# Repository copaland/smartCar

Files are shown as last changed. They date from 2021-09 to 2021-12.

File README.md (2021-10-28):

# smartCar
Arduino Bluetooth controlled 2WD smart Car

1. Ultrasonic sensor
2. Bluetooth controlled with Button App
3. Bluetooth controlled with Joystic App  

[AF Motor Shield Library] https://github.com/adafruit/Adafruit-Motor-Shield-library

https://arduino.esp8266.com/stable/package_esp8266com_index.json

https://github.com/stm32duino/BoardManagerFiles/raw/master/package_stmicroelectronics_index.json,https://mcudude.github.io/MiniCore/package_MCUdude_MiniCore_index.json,https://arduino.esp8266.com/stable/package_esp8266com_index.json

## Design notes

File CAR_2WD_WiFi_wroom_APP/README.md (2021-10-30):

 ##  2WD CAR ESP WiFi 버튼 제어 프로그램
 
Board : ESP-WROOM-02 D1  
Driver : TB6612  
Library : WiFiCar_TB6612  

D0  16 LED PULLUP 10K  
D1  5 TRIG  
D2  4 ECHO  
D3  0      FLASH  
D4  2      (SDA)  
D5  14 AIN (SCL)  
D6  12 APWM  
D7  13 BPWM  
D8  15 BIN PULLDOWN 10K   
D9  TX 1 RXD BT  
D10 RX 3 TXD BT  

* Board manager URL
https://arduino.esp8266.com/stable/package_esp8266com_index.json

* Board
LOLIN(Wemos) D1 & R2 & mini

* Library 
https://github.com/copaland/smartCar/blob/main/WiFiCar_TB6612-master.zip

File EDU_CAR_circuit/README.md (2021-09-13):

## ESP-WROOM-02 BASE Smat Car Kit

### 1.KiCad 설치 : 회로도 작성, PCB 설계
### 2.Arduino 설치 : Firmware 프로그래밍
### 3.MIT APP Inventor

### ESP-WROOM-02 PIN MAP
1-A0     SENS  
2-D1   5 TRIG  
3-D2   4 ECHO  
4-D3   0 LEFT SENS(FLASH)   
5-D4   2 RIGHT SENS(SDA)  
6-D5  14 AIN(SCL)  
7-D6  12 APWM   
8-D7  13 BPWM   
9-D8  15 BIN    
10-D9  3 RX  BT  
11-D10 1 TX  BT
13-D0 16 LED (Default)  

### Use KiCad virsion 5.1.10 
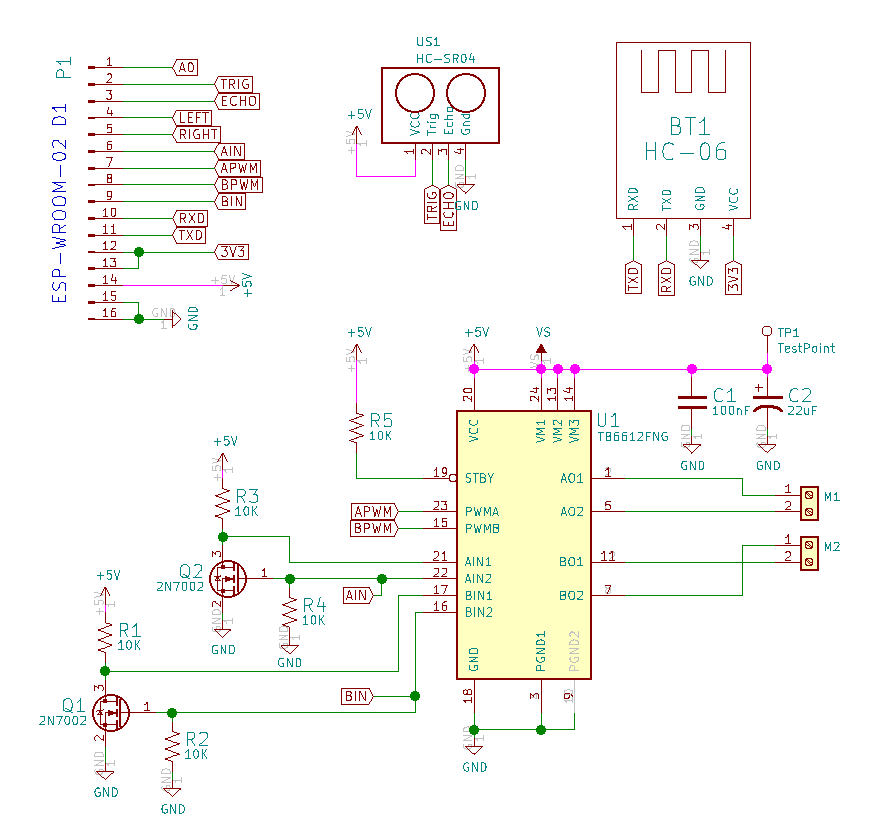
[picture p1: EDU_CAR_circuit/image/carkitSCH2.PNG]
회로도
  
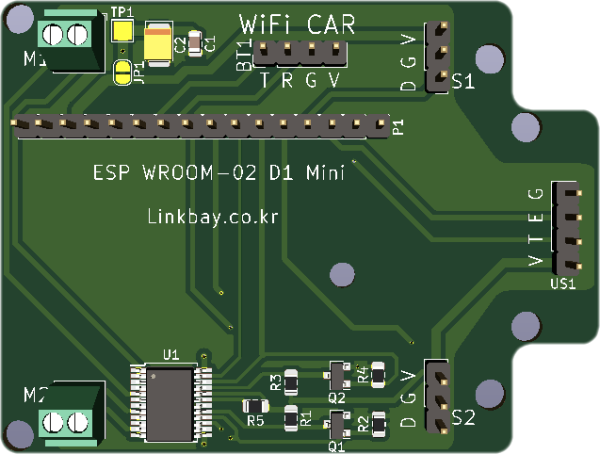
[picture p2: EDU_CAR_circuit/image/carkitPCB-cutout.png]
PCB
  
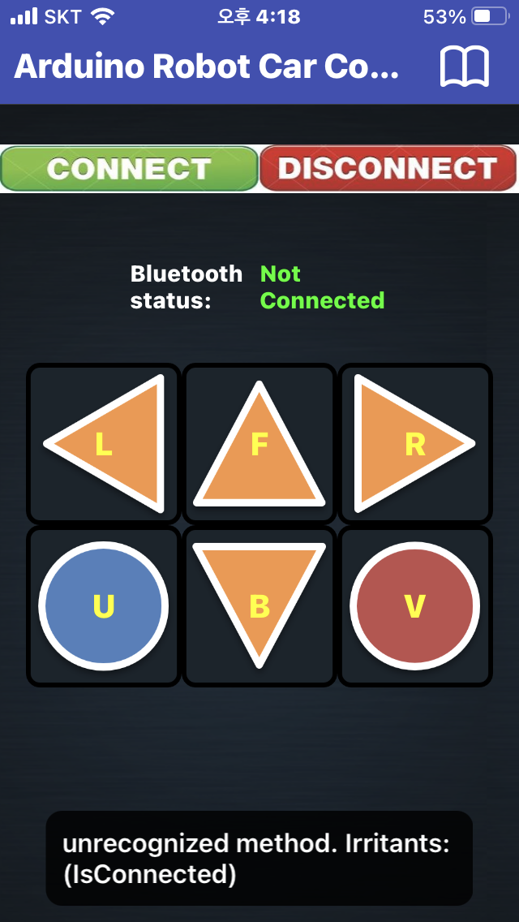
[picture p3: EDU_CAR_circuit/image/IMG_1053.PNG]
APP


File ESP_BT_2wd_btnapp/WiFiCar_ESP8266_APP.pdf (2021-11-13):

2021-11-13

1

# 3. IoT 앱 인벤터

## 김랑기 명장

# Smart IoT

## 학습내용

## 1. 앱인벤터 개요 2. 하드웨어 조립 및 테스트 3. 앱 인벤터 프로그램

학습목표
1. 아두이노로 모터를 제어하는 코딩을 작성할 수 있다. 2. 모터제어 하드웨어를 조립하고 테스트할 수 있다. 3. 앱인벤터 프로그램으로 앱을 만들고 원격으로 제어 할 수 있다. | 2

1

2

2

1

# 앱 인벤터의 개요

3

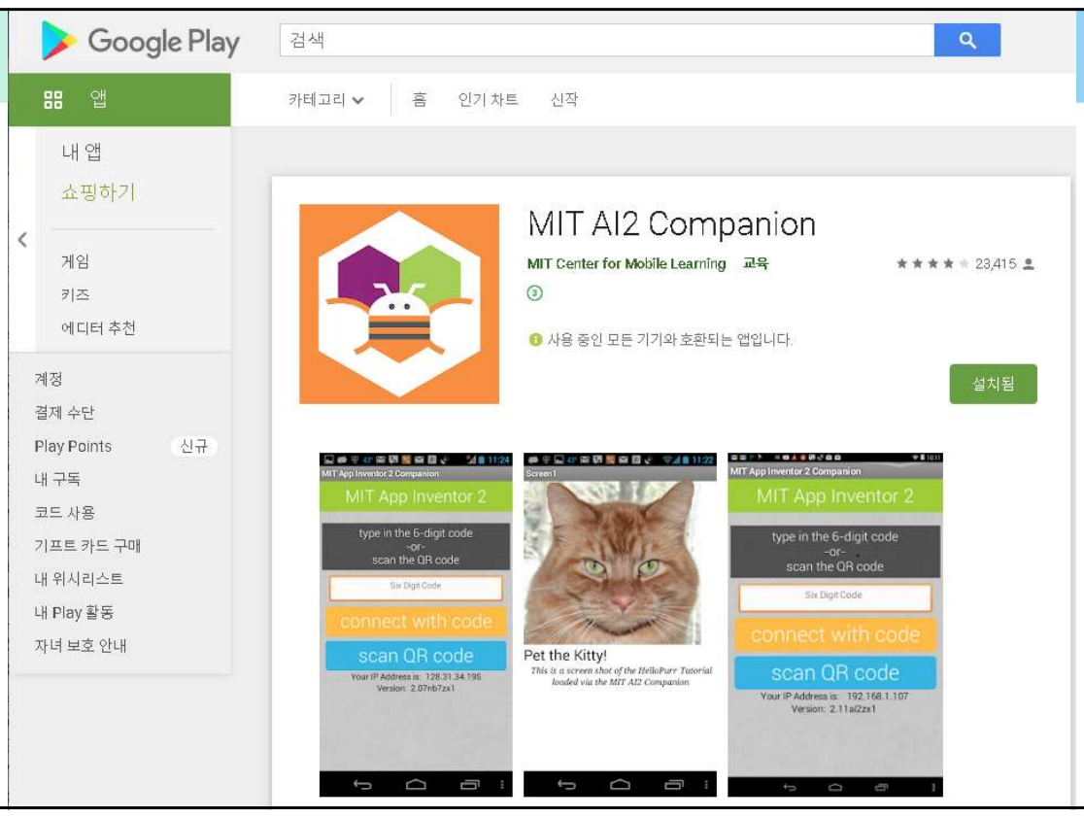
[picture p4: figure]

## 1.앱설치

3

4

3

## 2.앱인벤터 가입

### https://appinventor.mit.edu/

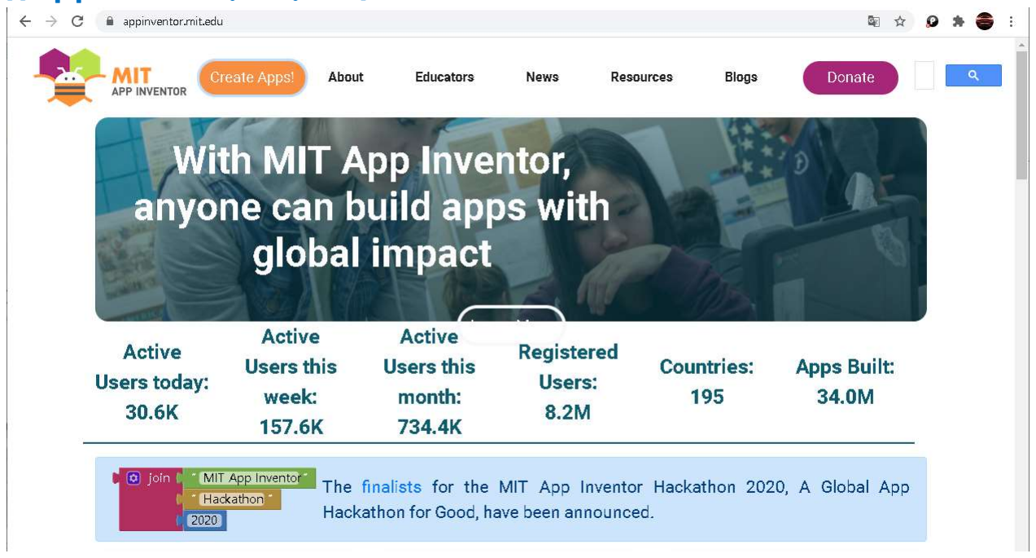
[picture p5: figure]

# 1. 앱 인벤터의 개요

## 앱 인벤터의 역사

2010년 12월 15일에 공식
출시되어 2011년에 구글이 소스
코드 공개. MIT에서 관리하기 시작, 2012년

3월에 MIT 버전의 앱 인벤터가
시작. MIT는 2013년 12월 ‘앱 인벤터2’

출시. 약 2,200 만 개의 앱을 만든 195

개국에서 온 40 만 명 이상의 월간
활성 사용자

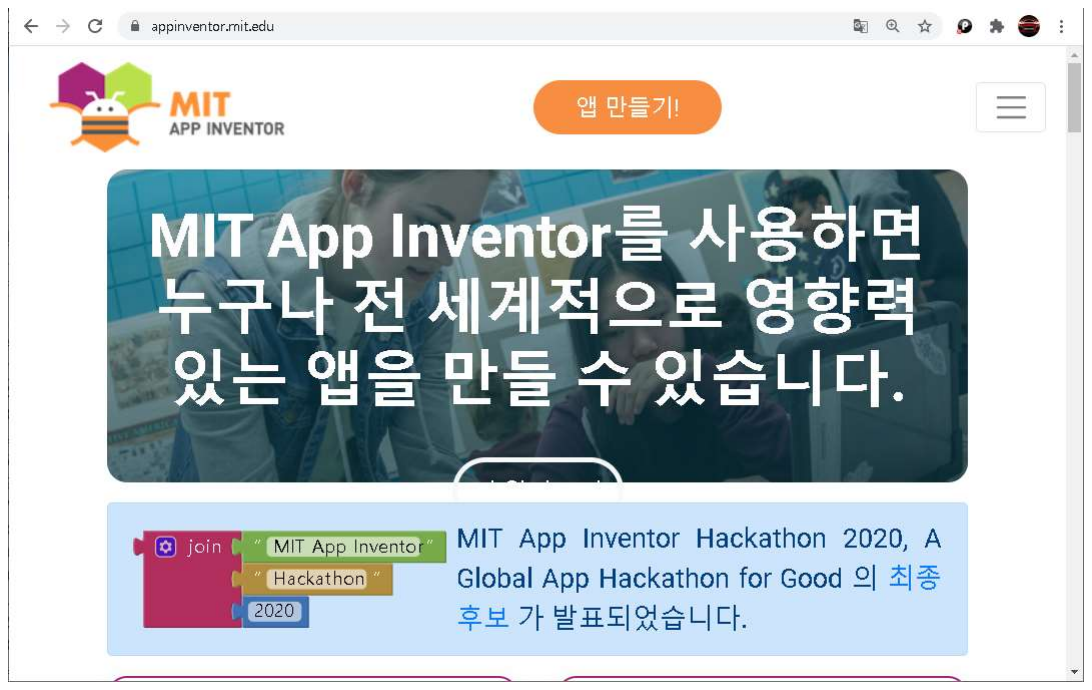
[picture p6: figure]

6

### https://appinventor.mit.edu

5

6

4

# 1. 앱 인벤터의 개요

## 앱 인벤터의 특징

드래그 앤 드롭 방식의 프로그래밍
웹 사이트에 접속하여 GUI 방식으로 앱의 외형을 디자인하고 앱의 동작은 블록을 맞추며 프로그래밍 이벤트 기반 프로그래밍
대부분은 사용자의 스크린 터치나 여러 센서를 통한 입력 등을 이벤트로 받아 처리하는 방식으로 동작. 앱 화면 디자인과 코딩 기능을 함께 제공

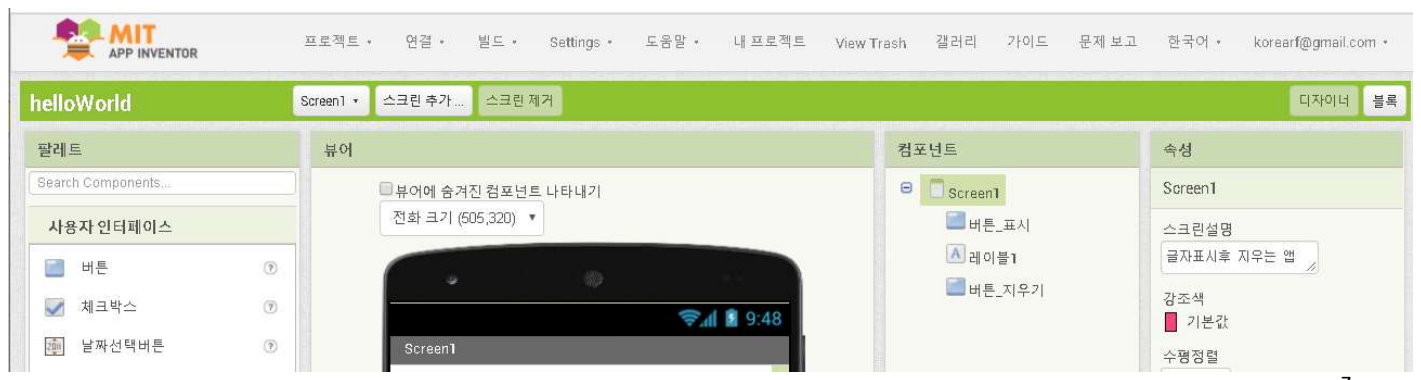
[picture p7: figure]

7

# 1. 앱 인벤터의 개요

## 앱 인벤터 사용을 위한 준비

## ①크롬 브라우저 설치, 구글 계정 준비하기 ②인벤터 웹 사이트에 접속하기 https://appinventor.mit.edu/ ③서비스 약관에 동의하기 ④설문 조사 실시하기 ⑤환영 메시지 창 확인하기 ⑥앱 인벤터 시작하기 ⑦앱 인벤터의 언어를 한글로 설정하기 ⑧앱 인벤터 사용 준비 완료하기

8

7

8

5

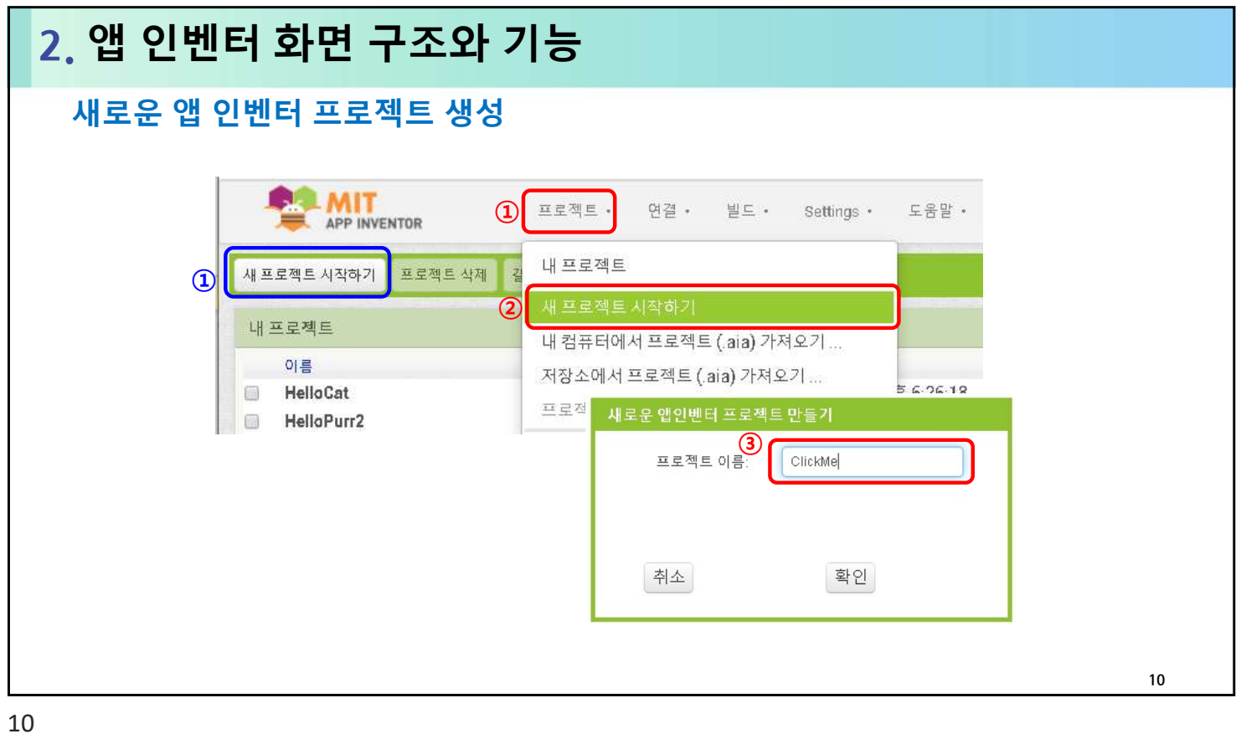
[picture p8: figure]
2. 앱 인벤터 화면 구조와 기능; 새로운 앱 인벤터 프로젝트 생성

6

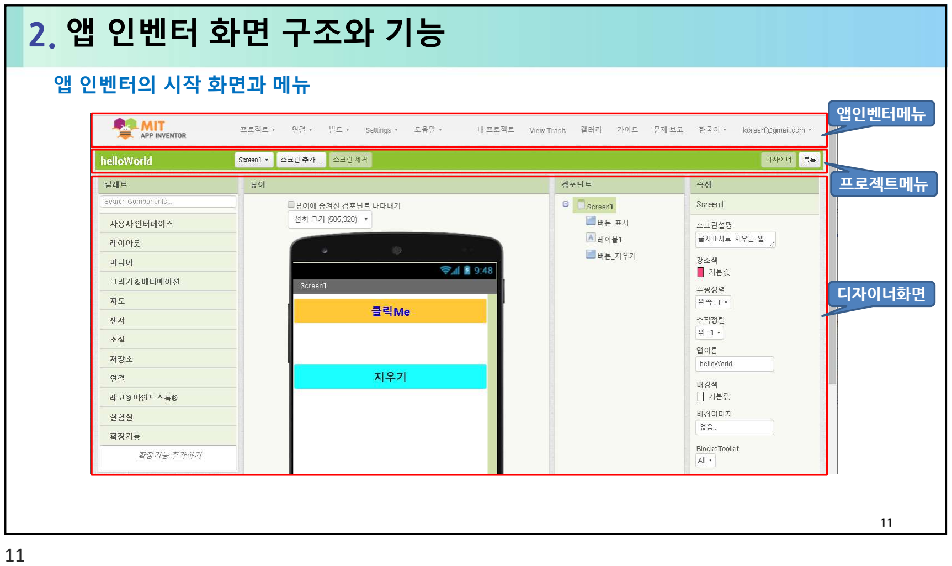
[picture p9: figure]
2. 앱 인벤터 화면 구조와 기능; 앱 인벤터의 시작 화면과 메뉴; 앱인벤터메뉴; 프로젝트메뉴; 디자이너화면

# 3.앱 실행하기-테스트 방법 3가지

12

https://appinventor.mit.edu/explore/ai2/setup

에뮬레이터(안드로이드기기 없을때) | USB케이블( WiFi 연결 없을때)

12

7

# 3.앱 실행하기-1

AI 컴패니언 사용하기 (동일한 WiFi 네트워크) 스마트폰 스토어에서 “MIT AI2” 검색
MIT AI2 컴패니언 앱 설치하고 실행

[연결]-[AI컴패니언]
‘Scan QR code’ 버튼 누르고
생성된 QR코드 찍으면 실행됨

13

# 3.앱 실행하기-2

에뮬레이터 사용하기(안드로이드 기기 없을때)
App Inventor 설정 소프트웨어 설치
https://appinventor.mit.edu/explore/ai2/setup-emulator
aiStarter 시작(검정 창은 닫지 말고 최소화)
Mac에서는 계정에 로그인하면 aiStarter가 자동으로 시작되고 보이지 않게 백그라운드에서 실행 Windows의 경우 데스크탑, 시작 메뉴, 모든 프로그램 및 시작 폴더에서 aiStarter에 대한 바로 가기
GNU / Linux에서 aiStarter는 / usr / google / appinventor / commands-for-Appinventor 폴더에 있으며 수동으로 시작
App Inventor 프로젝트를 열고 에뮬레이터에 연결

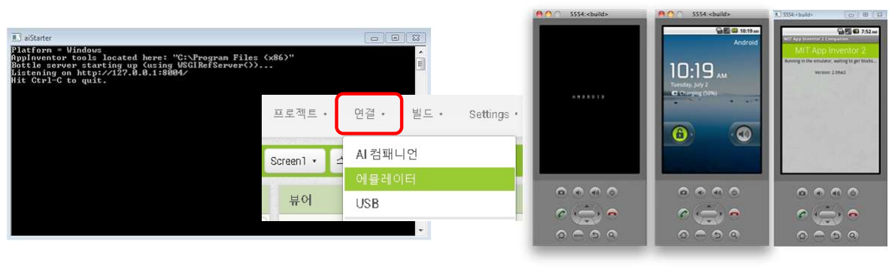
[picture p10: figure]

14

13

14

8

# 3. 앱 실행하기-3

USB케이블 사용하기
폰에 MIT AI2 컴패니언 앱 설치하고 실행
App Inventor 설정 소프트웨어 설치
https://appinventor.mit.edu/explore/ai2/setup-emulator aiStarter 시작(검정 창은 닫지 말고 최소화)
USB장치 설정
[설정]-[휴대전화정보]-[소프트웨어정보]
-빌드번호 7번 누르면 개발자 옵션이 나타남. [개발자옵션]USB디버깅 켬

연결할 때 "확인"을 누름

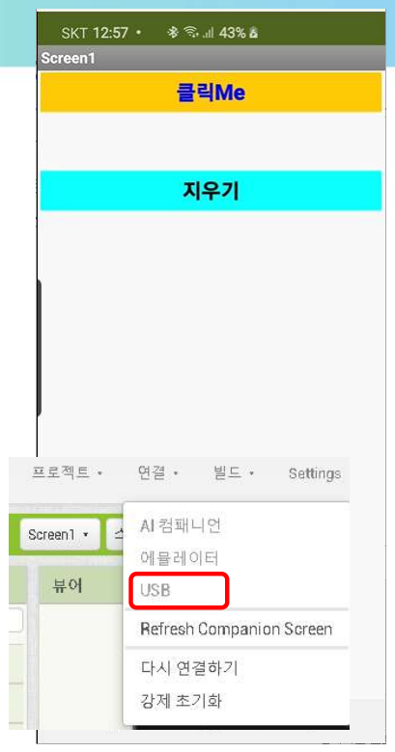
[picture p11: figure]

15

II

# 간단 앱 만들기 1

16

15

16

9

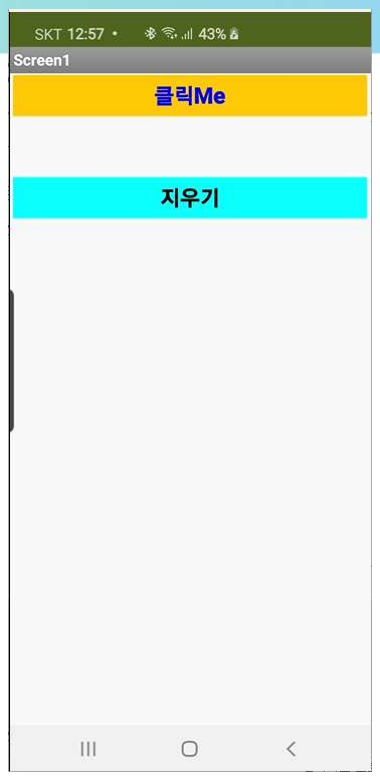
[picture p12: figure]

# 01.앱 기능정의

기능
버튼으로 자기소개를 표시하는 앱

## 입출력

클릭미 버튼을 누르면 자기소개 표시
지우기 버튼을 누르면 표시내용 삭제

## 컴포넌트

버튼, 레이블

## 리소스

없음

17
17

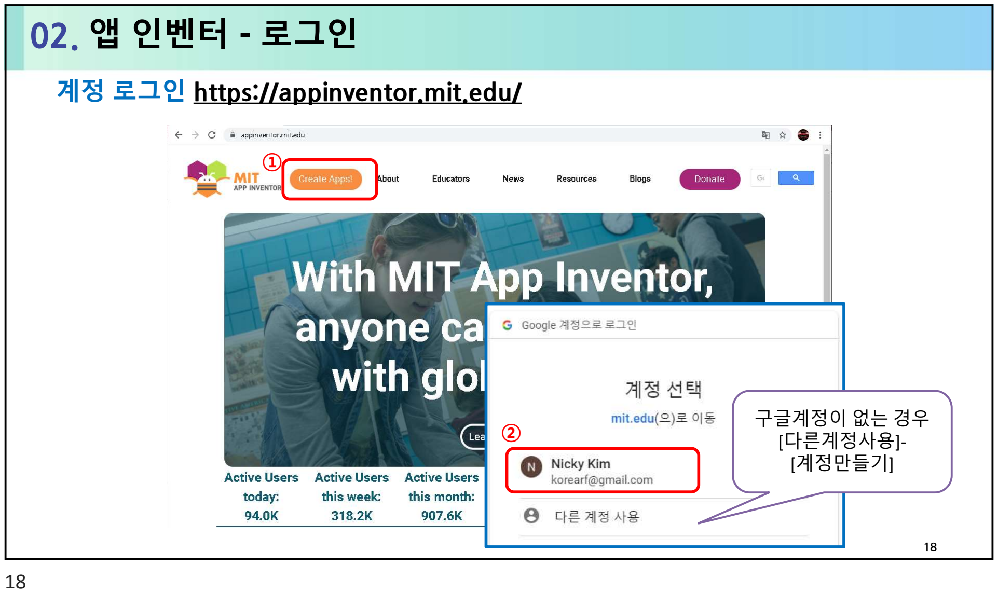
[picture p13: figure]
02. 앱 인벤터 - 로그인; 계정 로그인 https://appinventor.mit.edu/; 18 구글계정이 없는 경우 [다른계정사용]- [계정만들기]

10

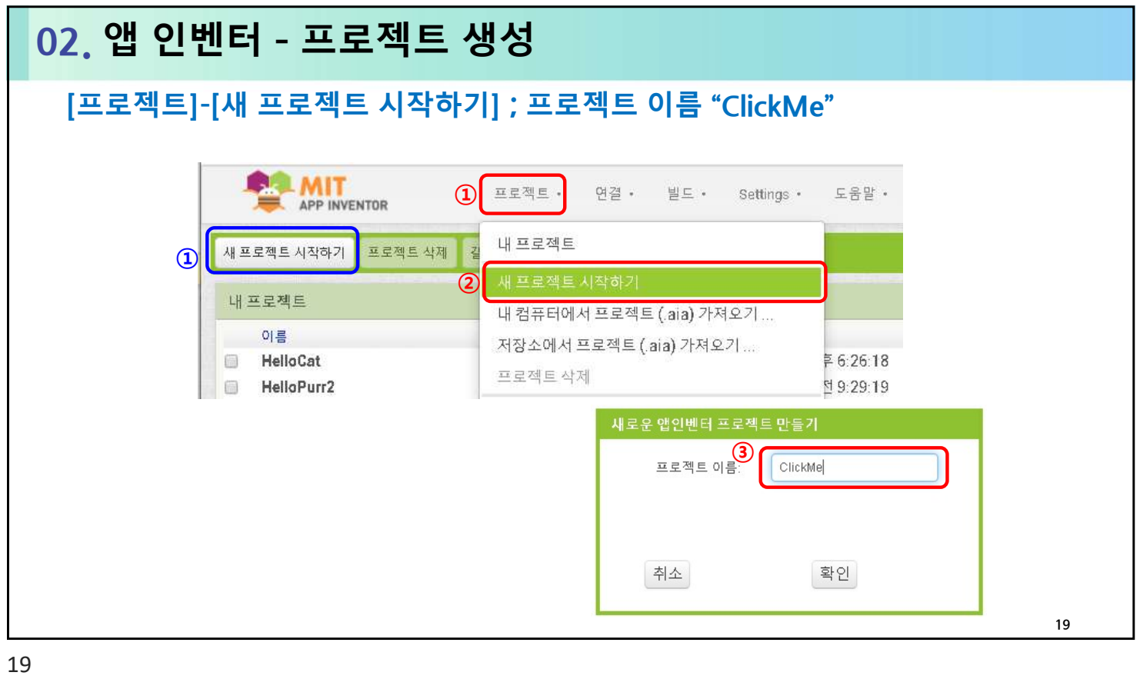
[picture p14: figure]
02. 앱 인벤터 – 프로젝트 생성

## [프로젝트]-[새 프로젝트 시작하기] ; 프로젝트 이름 “ClickMe”

# 03. 앱 인벤터 – 화면 설계

20
20

11

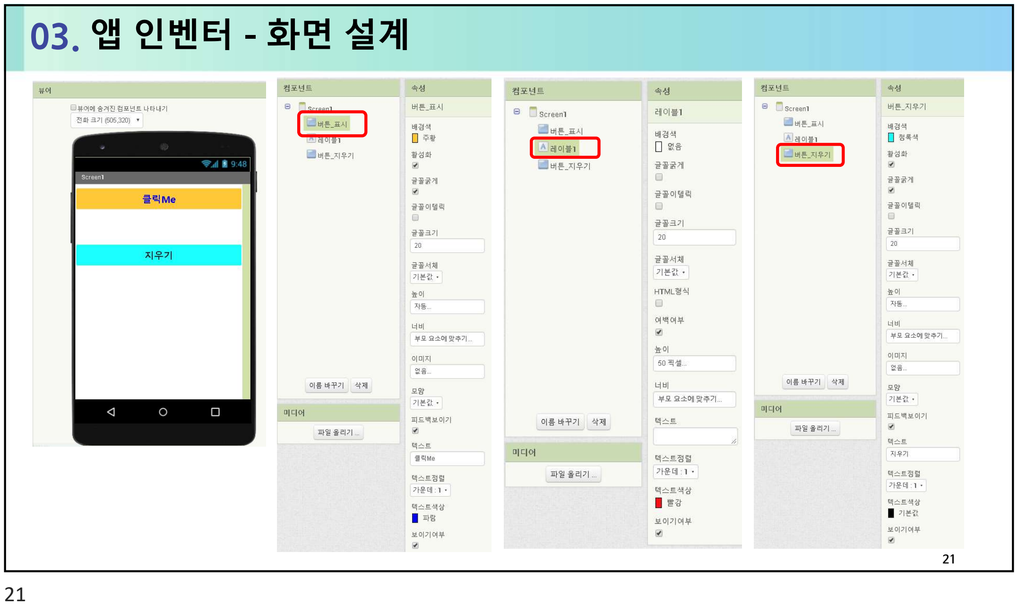
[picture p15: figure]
03. 앱 인벤터 – 화면 설계

# 04. 앱 인벤터 – 블록 코딩

이벤트 블록 : 컴포넌트에 특정 이벤트가 발생했을 때 호출되는 블록

값 지정하기 블록 : 컴포넌트의 속성에 값을 지정하는 블록

값 블록 : 특정한 값을 표시하는 블록

22
22

12

II

# 간단 앱 만들기 2

23

# 01.앱기능정의

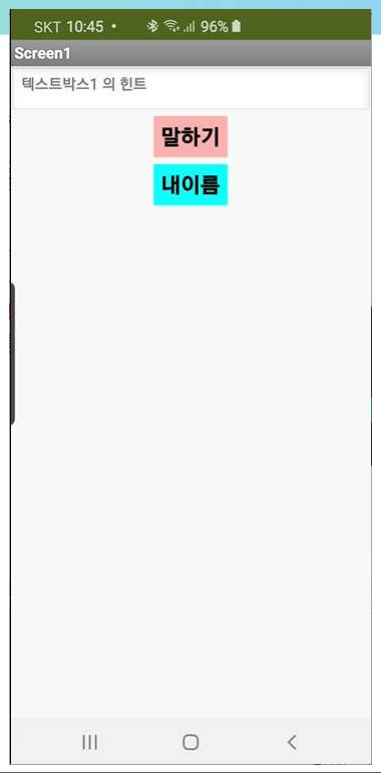
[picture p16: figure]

기능

텍스트를 음성으로 변환하는 앱

## 입출력

텍스트박스에 글자를 입력하고
말하기 버튼을 누르면 음성출력
내이름 버튼은 미리 저장된 텍스트 출력
폰을 흔들면 입력된 내용 음성출력

## 컴포넌트

텍스트박스, 버튼, 음성변환, 가속도센서

## 리소스

없음

24

23

24

13

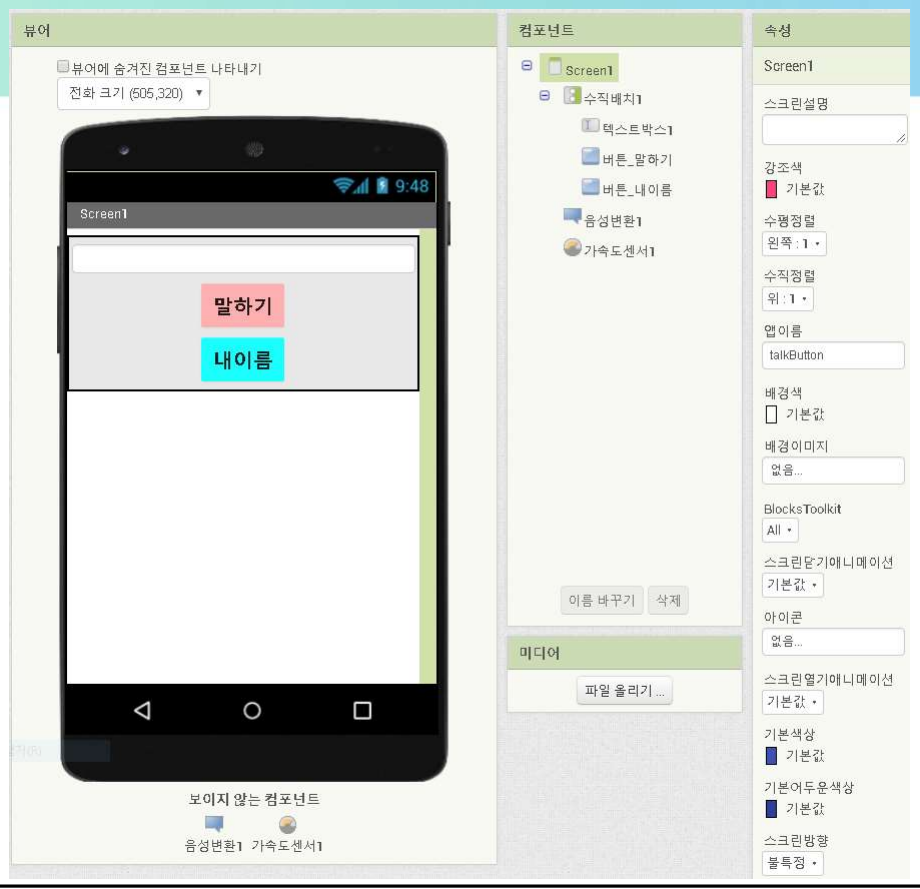
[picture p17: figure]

# 02.화면설계

25

## 수직배치 텍스트박스

버튼

## 음성변환 가속도 센서

# 03.블록 코딩

26

25

26

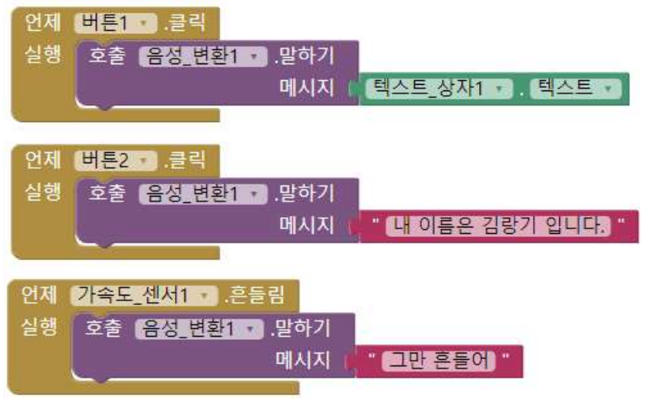
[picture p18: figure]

## 버튼 이미지 만들기

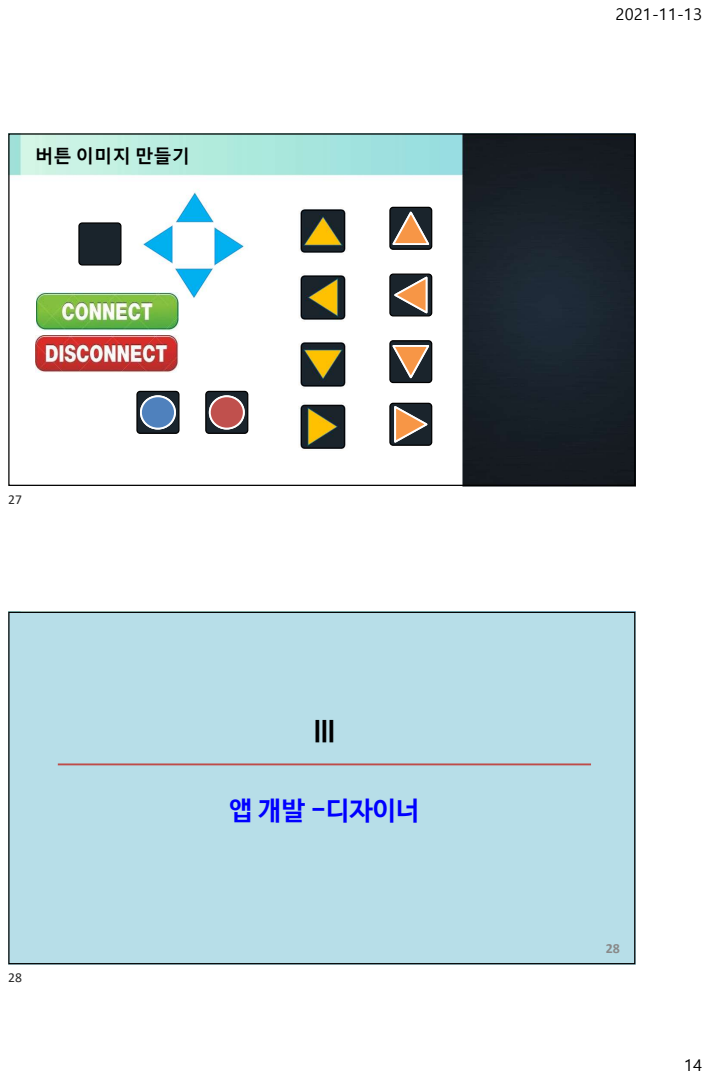
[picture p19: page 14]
III; 앱 개발 -디자이너

15

- 기능 버튼으로 자동차 방향 전환 제어 합니다. 램프 제어,켜짐/꺼짐
- 입출력 레이블에 제목 표시 블루투스 버튼
- 컴포넌트 레이블, 목록선택버튼,버튼, 블루투스,클락

### - 리소스

29

30

### - 프로젝트 이름 : SmartCarControl

29

30

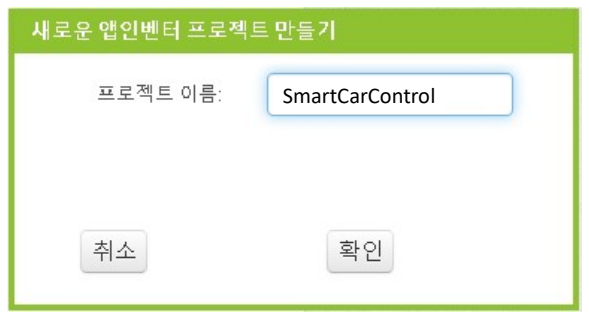
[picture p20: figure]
SmartCarControl

## 03.화면설계

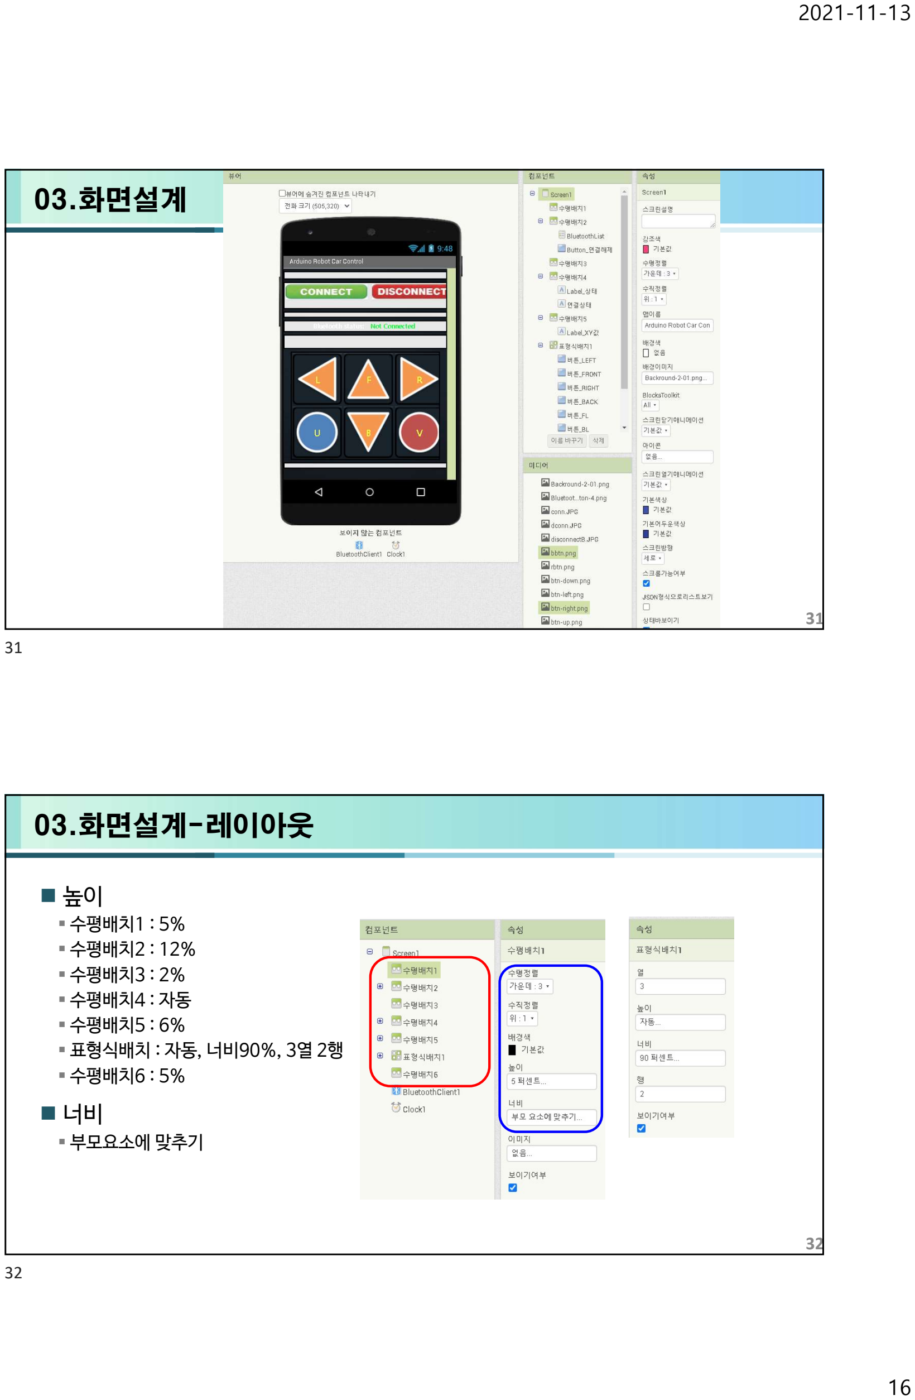
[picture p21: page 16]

16

31

## 03.화면설계-레이아웃

32

- 높이 수평배치1 : 5% 수평배치2 : 12% 수평배치3 : 2% 수평배치4 : 자동 수평배치5 : 6% 표형식배치 : 자동, 너비90%, 3열 2행 수평배치6 : 5%
- 너비 부모요소에 맞추기

31

32

## 03.화면설계-연결

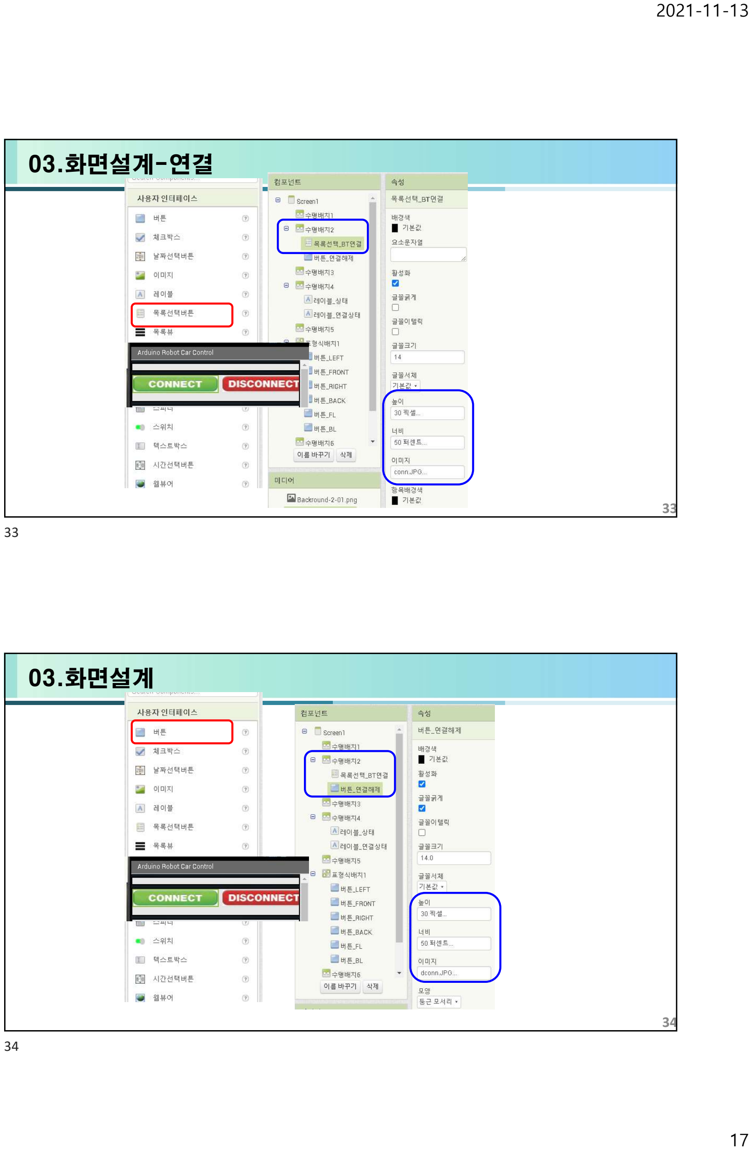
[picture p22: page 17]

17

33

## 03.화면설계

34

33

34

## 03.화면설계-상태

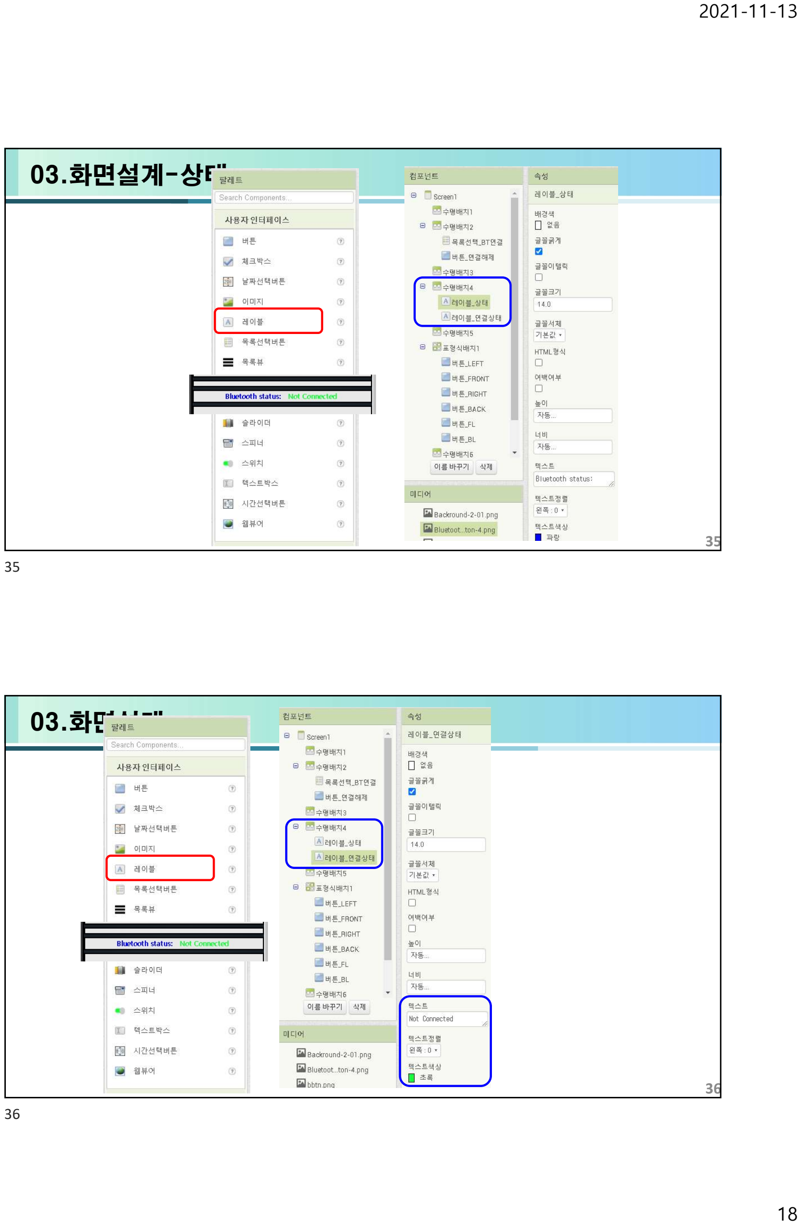
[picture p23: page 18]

18

35

## 03.화면설계

36

35

36

## 03.화면설계-버튼

- 3x2

19

37

## 03.화면설계

38

37

38

20

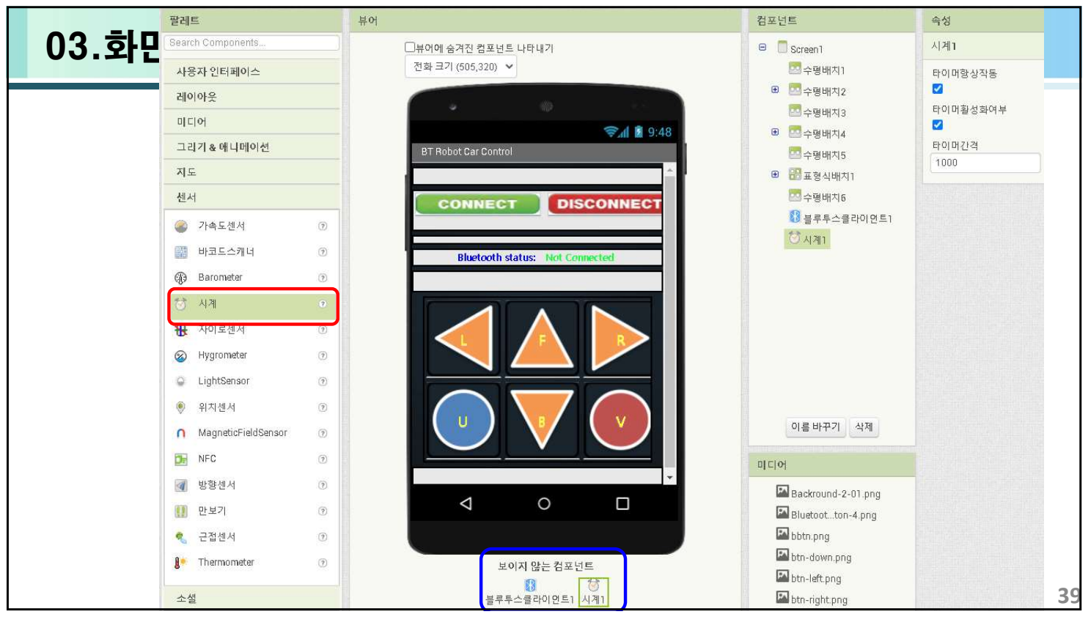
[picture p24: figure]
03.화면설계

# III

# 앱 개발 - 블록 코딩

40

39

40

## 03.블록 코딩


21

41

## 03.블록 코딩

42

41

42

## 03.블록 코딩


22

43

## 03.블록 코딩

44

43

44

## 04. 앱 다운로드


23

45

## 05.앱 테스트

46

### - 자동차 전원 on - 블루투스

45

46

24

47

### - 코드 및 앱 - https://github.com/copaland/smartCar

- https://github.com/copaland/smartCar/tree/main/ESP_BT_2wd_btnapp

Q&A

47

48

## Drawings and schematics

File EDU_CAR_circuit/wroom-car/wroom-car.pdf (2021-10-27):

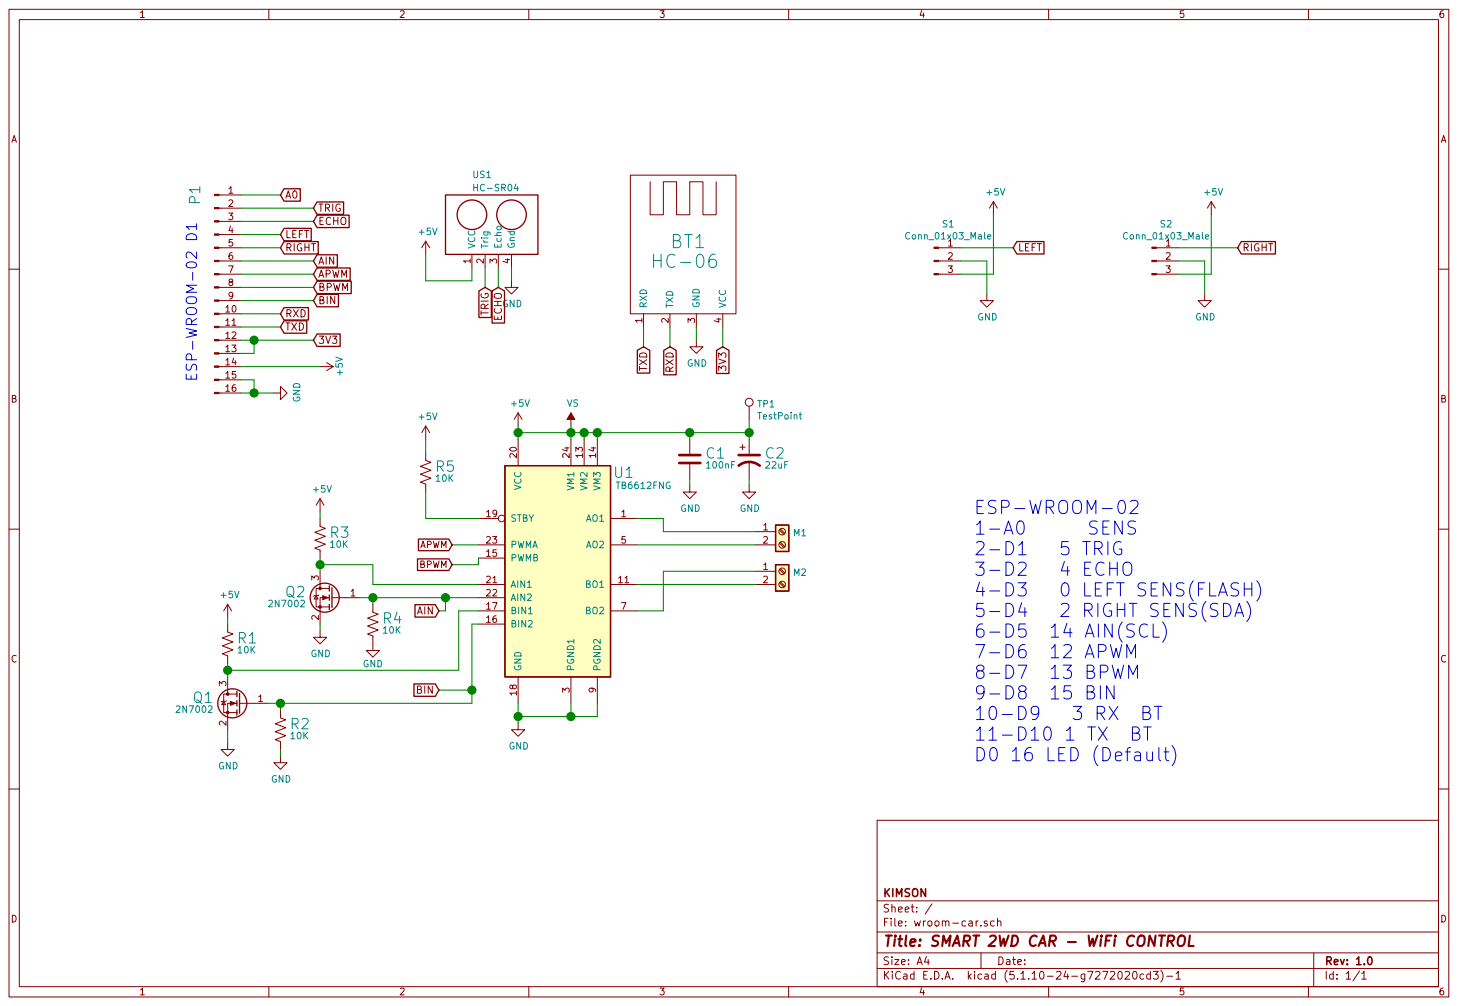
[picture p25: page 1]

File: wroom-car.sch Sheet: / KIMSON R4

Id: 1/1 Title: SMART 2WD CAR - WiFi CONTROL

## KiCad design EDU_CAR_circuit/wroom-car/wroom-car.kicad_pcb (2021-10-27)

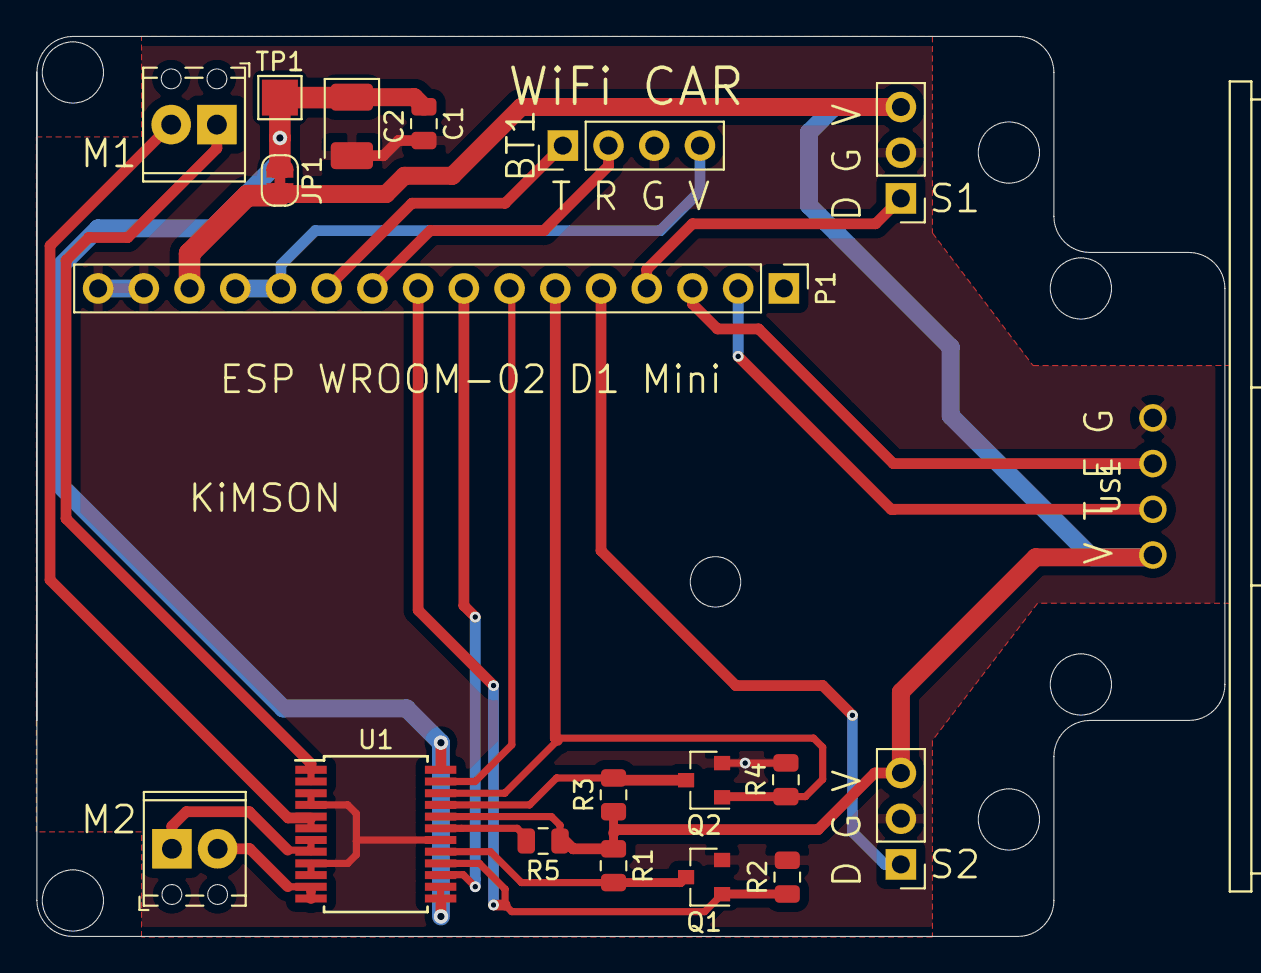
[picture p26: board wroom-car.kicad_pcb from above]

Board: 2 copper layers, 66.0 x 50.0 mm, 19 parts (0 on the bottom side), 21 nets.

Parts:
BT1: HC-06; PinHeader_1x04_P2.54mm_Vertical
C1: 100nF; C_0805_2012Metric
C2: 22uF; CP_EIA-3528-12_Kemet-T_Pad1.50x2.35mm_HandSolder
JP1: JP; SolderJumper-2_P1.3mm_Bridged_RoundedPad1.0x1.5mm
M1, M2: Screw_Terminal_01x02; TerminalBlock_Phoenix_MPT-0,5-2-2.54_1x02_P2.54mm_Horizontal
P1: Conn_01x16_Male; PinHeader_1x16_P2.54mm_Vertical
Q1, Q2: 2N7002; SOT-23
R1, R2, R3, R4, R5: 10K; R_0805_2012Metric
S1, S2: Conn_01x03_Male; PinHeader_1x03_P2.54mm_Vertical
TP1: TestPoint; TestPoint_Pad_2.0x2.0mm
U1: TB6612FNG; SSOP-24_5.3x8.2mm_P0.65mm
US1: HC-SR04

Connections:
3V3: BT1.4, P1.12, P1.13
+5V: JP1.2, P1.14, R1.1, R3.1, R5.1, S1.3, S2.3, U1.20, US1.1
AIN: P1.6, Q2.1, R4.1, U1.22
APWM: P1.7, U1.23
BIN: P1.9, Q1.1, R2.1, U1.16
BPWM: P1.8, U1.15
ECHO: P1.3, US1.3
GND: BT1.3, C1.2, C2.2, P1.15, P1.16, Q1.2, Q2.2, R2.2, R4.2, S1.2, S2.2, U1.3, U1.4, U1.9, U1.10, U1.18, US1.4
LEFT: P1.4, S1.1
unnamed: M1.1, U1.1, U1.2
unnamed: M1.2, U1.5, U1.6
unnamed: M2.1, U1.7, U1.8
unnamed: M2.2, U1.11, U1.12
unnamed: Q1.3, R1.2, U1.17
unnamed: Q2.3, R3.2, U1.21
unnamed: R5.2, U1.19
RIGHT: P1.5, S2.1
RXD: BT1.2, P1.10
TRIG: P1.2, US1.2
TXD: BT1.1, P1.11
VS: C1.1, C2.1, JP1.1, TP1.1, U1.13, U1.14, U1.24

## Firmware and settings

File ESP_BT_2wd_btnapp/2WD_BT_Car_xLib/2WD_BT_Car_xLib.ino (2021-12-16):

/*  20211216 ok final
 *  2WD 블루투스 버튼 제어 주행 프로그램 
 *  ESP-WROOM-02 D1
D0  16 LED PULLUP 10K
D1  5 TRIG
D2  4 ECHO
D3  0      FLASH
D4  2      (SDA)
D5  14 AIN (SCL)
D6  12 APWM
D7  13 BPWM
D8  15 BIN PULLDOWN 10K 
D9  TX 1 RXD BT
D10 RX 3 TXD BT
*/
#include <ESP8266WiFi.h>
//#include <WiFiCar_TB6612.h> //TB6612
#include <SoftwareSerial.h>

// pin settings
#define LED_PIN    16  //D0 
#define TRIG_PIN    5  //D1 ULTRASONIC
#define ECHO_PIN    4  //D2 

#define LDL_PIN    0   //D3 LEFT LED
#define LDR_PIN    2   //D4 RIGHT LED

#define DIR_A   14   //D5 TB6612
#define PWM_A   12   //D6 
#define PWM_B   13   //D7 
#define DIR_B   15   //D8 

#define RXD_PIN   3   //D9 BLUETOOTH TX 
#define TXD_PIN   1   //D10 BLUETOOTH RX

SoftwareSerial BT(RXD_PIN,TXD_PIN);//3RX, 1TX

//Motor M1(AIN_PIN, APWM_PIN, ADIR);//Left
//Motor M2(BIN_PIN, BPWM_PIN, BDIR);//Right

int motor_speed = 990;//motor speed 1023
char CMD = 'S'; //

bool LEDstatus = LOW;
boolean FL = false;
boolean FR = false;

void setup() { 
  pinMode(LED_PIN, OUTPUT);
  pinMode(TRIG_PIN, OUTPUT);
  pinMode(DIR_A, OUTPUT);
  pinMode(DIR_B, OUTPUT);
  pinMode(PWM_A, OUTPUT);
  pinMode(PWM_B, OUTPUT);
  
  pinMode(LDL_PIN, OUTPUT);
  pinMode(LDR_PIN, OUTPUT);
    
  digitalWrite(DIR_A, LOW);
  digitalWrite(DIR_B, LOW);
  digitalWrite(PWM_A, LOW);
  digitalWrite(PWM_B, LOW);
//for Test

  stop_motors();
  
  Serial.begin(9600); //Set the baud rate to your Bluetooth module.
  BT.begin(9600);   
} 

void loop(){ 

  if(BT.available() > 0) {
    CMD = BT.read();
    ///Serial.print(CMD);
  }

  if (FL) {digitalWrite(LED_PIN, HIGH);}
  if (!FL) {digitalWrite(LED_PIN, LOW);}

  ardu_action();
  delay(1);
}

void stop_motors() {
  analogWrite(PWM_A, 0);
  analogWrite(PWM_B, 0);
}

void forward() {
  analogWrite(PWM_A, motor_speed);
  analogWrite(PWM_B, motor_speed);
  digitalWrite(DIR_A, HIGH);
  digitalWrite(DIR_B, HIGH);
}

void backward() {
  analogWrite(PWM_A, motor_speed);
  analogWrite(PWM_B, motor_speed);
  digitalWrite(DIR_A, LOW);
  digitalWrite(DIR_B, LOW);
}

void turn_left() {
  analogWrite(PWM_A, 0);
  analogWrite(PWM_B, motor_speed);
  digitalWrite(DIR_A, HIGH);
  digitalWrite(DIR_B, HIGH);
}

void turn_right() {
  analogWrite(PWM_A, motor_speed);
  analogWrite(PWM_B, 0);
  digitalWrite(DIR_A, HIGH);
  digitalWrite(DIR_B, HIGH);
}

void turn_selfLeft() {
  analogWrite(PWM_A, motor_speed);
  analogWrite(PWM_B, motor_speed);
  digitalWrite(DIR_A, LOW);
  digitalWrite(DIR_B, HIGH);
}

void turn_selfRight() {
  analogWrite(PWM_A, motor_speed);
  analogWrite(PWM_B, motor_speed);
  digitalWrite(DIR_A, HIGH);
  digitalWrite(DIR_B, LOW);
}

void ardu_action() {
  if(CMD == 'F'){ forward(); }
  else if(CMD == 'B'){ backward(); }
  else if(CMD == 'L'){ turn_left(); }
  else if(CMD == 'R'){ turn_right(); }
  else if(CMD == 'U'){ turn_selfLeft(); }
  else if(CMD == 'V'){ turn_selfRight(); }
  else if(CMD == 'S'){ stop_motors(); }
  //else { motor_speed = 0; }
  delay(1);
}

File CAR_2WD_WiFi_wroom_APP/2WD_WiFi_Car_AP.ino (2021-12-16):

/*
//AP mode test OK 20211127 
//WiFi 2WD 자동차 APP 제어 프로젝트
Wifi Car controlled by a web server in AP Mode.
 MOVE:
 - http://<YourIP>:<YourPort>/move?dir=F (Forward)
 - http://<YourIP>:<YourPort>/move?dir=B (Bacward)
 
 ACTION:
 - http://<YourIP>:<YourPort>/action?type=1 (Action 1)
 - http://<YourIP>:<YourPort>/action?type=2 (Action 2)
 
ESP-WROOM-02 D1
D0  16 LED PULLUP 10K
D1  5 TRIG
D2  4 ECHO
D3  0      FLASH
D4  2      (SDA)
D5  14 AIN (SCL)
D6  12 APWM
D7  13 BPWM
D8  15 BIN PULLDOWN 10K 
D9  TX 1 RXD BT
D10 RX 3 TXD BT
*/

#include <ESP8266WiFi.h>
#include <ESP8266WebServer.h>
//#include <WiFiCar_TB6612.h>

// pin settings
#define LED_PIN    16  //D0 
#define TRIG_PIN    5  //D1 ULTRASONIC
#define ECHO_PIN    4  //D2 

#define LDL_PIN    0   //D3 LEFT LED
#define LDR_PIN    2   //D4 RIGHT LED

#define DIR_A   14   //D5 TB6612
#define PWM_A   12   //D6 
#define PWM_B   13   //D7 
#define DIR_B   15   //D8 

//const int ADIR = 1; //Value can be 1 or -1
//const int BDIR = 1;

// WiFi settings
const char *ssid      = "WiFi-CAR"; // for AP mode SSID
const char *password  = "12345678"; // for AP mode PSWD

IPAddress localIp(192, 168, 4, 1); //IP for AP mode
IPAddress netMask(255, 255, 255, 0); //IP for AP mode
const int port = 8080; // Port
ESP8266WebServer server(port);

//TB6612
//Motor M1(DIR_A, PWM_A, ADIR);//Left
//Motor M2(DIR_B, PWM_B, BDIR);//Right


///String CMD = ""; //add
///char charBuf[3];

int motor_speed = 990;//motor speed 1023
char CMD = 'S'; //
//char set_mode = 'S'; //0 select mode action
bool LEDstatus = LOW;
boolean FL = false;
boolean FR = false;


// initialize
void setup() {
  WiFi.mode(WIFI_AP);
  WiFi.softAPConfig(localIp, localIp, netMask);
  WiFi.softAP(ssid, password);
    
  Serial.begin(9600);
  Serial.println("Wifi Control");

  pinMode(LED_PIN, OUTPUT);
  pinMode(TRIG_PIN, OUTPUT);
  pinMode(DIR_A, OUTPUT);
  pinMode(DIR_B, OUTPUT);
  pinMode(PWM_A, OUTPUT);
  pinMode(PWM_B, OUTPUT);
  
  pinMode(LDL_PIN, OUTPUT);
  pinMode(LDR_PIN, OUTPUT);
    
  digitalWrite(DIR_A, LOW);
  digitalWrite(DIR_B, LOW);
  digitalWrite(PWM_A, LOW);
  digitalWrite(PWM_B, LOW); 
  
  server.on("/move", HTTP_GET, handleMoveRequest);
  server.on("/action", HTTP_GET, handleActionRequest);
  server.onNotFound(handleNotFound);
  server.begin();

  stop_motors();
}

void loop() {
    server.handleClient();
 /*   
    CMD = server.arg("State");
    //Serial.println(CMD);//for test
    
    ardu_action();
 */  
   ardu_action();
   //delay(1);
}

void handleMoveRequest() {
  if (!server.hasArg("dir")) {
    server.send(404, "text / plain", "Move: undefined");
    return;
  }
  String direction = server.arg("dir");
  if (direction.equals("F")) {
    CMD = 'F'; //forward();
    server.send(200, "text / plain", "Move: forward");
  }
  else if (direction.equals("B")) {
    CMD = 'B'; //backward();
    server.send(200, "text / plain", "Move: backward");
  }
  else  if (direction.equals("S")) {
    CMD = 'S'; //stop_motors();
    server.send(200, "text / plain", "Move: stop");
  }
  else  if (direction.equals("L")) {
    CMD = 'L'; //turn_left();
    server.send(200, "text / plain", "Turn: Left");
  }
  else  if (direction.equals("R")) {
    CMD = 'R'; //turn_right();
    server.send(200, "text / plain", "Turn: Right");
  }
  else  if (direction.equals("U")) {
    CMD = 'U'; //turn_selfLeft();
    server.send(200, "text / plain", "Turn: Self Left");
  }
  else  if (direction.equals("V")) {
    CMD = 'V'; //turn_selfRight();
    server.send(200, "text / plain", "Turn: Self Right");
  }  
  else {
    server.send(404, "text / plain", "Move: undefined");
  }
}

void handleActionRequest() {
  if (!server.hasArg("type")) {
    server.send(404, "text / plain", "Action: undefined");
    return;
  }
  String type = server.arg("type");
  if (type.equals("1")) {
    // TODO : Action 1
    server.send(200, "text / plain", "Action 1");
  }
  else if (type.equals("2")) {
    // TODO : Action 2
    server.send(200, "text / plain", "Action 2");
  }
  else if (type.equals("3")) {
    // TODO : Action 3
    server.send(200, "text / plain", "Action 3");
  }
  else if (type.equals("4")) {
    // TODO : Action 4
    server.send(200, "text / plain", "Action 4");
  }
  else if (type.equals("5")) {
    // TODO : Action 5
    server.send(200, "text / plain", "Action 5");
  }
  else if (type.equals("6")) {
    // TODO : Action 6
    server.send(200, "text / plain", "Action 6");
  }
  else if (type.equals("7")) {
    // TODO : Action 7
    server.send(200, "text / plain", "Action 7");
  }
  else if (type.equals("0")) {
    // TODO : Action 0
    server.send(200, "text / plain", "Action 0");
  }
  else {
    server.send(404, "text / plain", "Action: undefined");
  }
}

// 
void handleNotFound() {
  //Serial.println("Page error");
  server.send(404, "text/plain", "404: Not found");
}

void stop_motors() {
  analogWrite(PWM_A, 0);
  analogWrite(PWM_B, 0);
}

void forward() {
  analogWrite(PWM_A, motor_speed);
  analogWrite(PWM_B, motor_speed);
  digitalWrite(DIR_A, HIGH);
  digitalWrite(DIR_B, HIGH);
}

void backward() {
  analogWrite(PWM_A, motor_speed);
  analogWrite(PWM_B, motor_speed);
  digitalWrite(DIR_A, LOW);
  digitalWrite(DIR_B, LOW);
}

void turn_left() {
  analogWrite(PWM_A, 0);
  analogWrite(PWM_B, motor_speed);
  digitalWrite(DIR_A, HIGH);
  digitalWrite(DIR_B, HIGH);
}

void turn_right() {
  analogWrite(PWM_A, motor_speed);
  analogWrite(PWM_B, 0);
  digitalWrite(DIR_A, HIGH);
  digitalWrite(DIR_B, HIGH);
}

void turn_selfLeft() {
  analogWrite(PWM_A, motor_speed);
  analogWrite(PWM_B, motor_speed);
  digitalWrite(DIR_A, LOW);
  digitalWrite(DIR_B, HIGH);
}

void turn_selfRight() {
  analogWrite(PWM_A, motor_speed);
  analogWrite(PWM_B, motor_speed);
  digitalWrite(DIR_A, HIGH);
  digitalWrite(DIR_B, LOW);
}

void ardu_action() {
  if(CMD == 'F'){ forward(); }
  else if(CMD == 'B'){ backward(); }
  else if(CMD == 'L'){ turn_left(); }
  else if(CMD == 'R'){ turn_right(); }
  else if(CMD == 'U'){ turn_selfLeft(); }
  else if(CMD == 'V'){ turn_selfRight(); }
  else if(CMD == 'S'){ stop_motors(); }
  //else { motor_speed = 0; }
  delay(1);
}
/*
 void ardu_action() {
  if(CMD == "F"){ forward(M1, M2, SPEED); }
  else if(CMD == "B"){ SPEED = 980; backward(M1, M2, SPEED); }
  else if(CMD == "L"){ SPEED = 980; left(M1, M2, SPEED); }
  else if(CMD == "R"){ SPEED = 980; right(M1, M2, SPEED); }
  else if(CMD == "U"){ SPEED = 980; selfLeft(M1, M2, SPEED); }
  else if(CMD == "V"){ SPEED = 980; selfRight(M1, M2, SPEED); }
  else if(CMD == "S"){ SPEED = 0; brake(M1, M2); }
  else { SPEED = 0; brake(M1, M2); }
  delay(1);
}
*/

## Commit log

2021-08-09 2WD bluetooth controlled smart car
    # 2WD bluetooth controlled smart car
    1.Ultrasonic Sensor
    2.Bluetooth Control & Button App
    3.Bluetooth Control & Joystic App
2021-09-13 ESP WROOM SMART CAR CIRCUIT
    KiCad circuits and PCBs are uploaded as unfinished files for learning.
    [wroom-car.kicad_pcb, wroom-car.sch]
2021-09-13 ADD PINMAP & CIRCUIT
    ADD PINMAP & CIRCUIT
2021-09-29 Button Image
    Button image to create app
2021-09-29 Upload Button image
    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
2021-09-29 Bluetooth button control Apk
    Bluetooth button control Apk file for SmartCar
2021-10-27 Upload files New
    빠진 부품 수정함
    [wroom-car.kicad_pcb, wroom-car.sch]
2021-10-28 TB6612 MOTOR DRIVE LIBRARY FILES
    Upload TB6612 MOTOR DRIVE LIBRARY FILES
2021-10-30 Create README.md
    설명서 추가
2021-11-22 2WD Car Project for ESP-Wroom
    Bluetooth Controlled 2WD Car Project for ESP-Wroom Board
